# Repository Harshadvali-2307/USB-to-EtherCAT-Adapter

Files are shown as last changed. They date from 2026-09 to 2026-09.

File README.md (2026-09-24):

# USB-to-EtherCAT-Adapter
STM32-based USB to EtherCAT adapter board using the LAN9252 EtherCAT controller.
Topics:
ethercat stm32 lan9252 usb embedded-systems pcb-design hardware industrial-automation electronics
Hardware design files and documentation for a USB-to-EtherCAT adapter board based on STM32 and LAN9252.

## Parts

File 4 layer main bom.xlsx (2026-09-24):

Reference | Value | Datasheet | Footprint | DNP | Exclude from BOM | Exclude from Board | Qty | manufacture number | MANUFACTURER
C1,C2,C3,C4,C20,C21 | 12pF | ~https://datasheets.kyocera-avx.com/600S.pdf | Capacitor_SMD:C_0805_2012Metric |  |  |  | 6 | 600S120JT250XT4K | KYOCERA AVX
C5 | 2.2uF | https://www.mouser.in/datasheet/3/72/1/T491C335K036AT.pdf | Capacitor_SMD:C_0805_2012Metric |  |  |  | 1 | 0805X225M100CT | Walsin
C6,C7,C8,C9,C10,C11,C14,C15,C16,C19,C22,C23,C24,C25,C26,C27,C30,C31,C32,C33,C34,C35 | 0.1uF | ~https://mm.digikey.com/Volume0/opasdata/d220001/medias/docus/6490/3372_0805B104K500BD.pdf | Capacitor_SMD:C_0805_2012Metric |  |  |  | 22 | 0805B104K500BD | Aillen
C12,C13 | 0.022uF | https://mm.digikey.com/Volume0/opasdata/d220001/medias/docus/5660/3372_0805B223K101BD.pdf | Capacitor_SMD:C_0805_2012Metric |  |  |  | 2 | 0805B223K101BD | Aillen
C17,C18 | 10uF | https://www.mouser.in/datasheet/3/72/1/KEM_T2009_T495.pdf,~ | Capacitor_SMD:C_1206_3216Metric |  |  |  | 2 | T495C106M025ATE300 | KEMET
C28 | 1uF | https://mm.digikey.com/Volume0/opasdata/d220001/medias/docus/5660/3372_0805B105K100CC.pdf | Capacitor_SMD:C_0805_2012Metric |  |  |  | 1 | 0805B105K100CC | Aillen
C29 | 470pF | ~https://mm.digikey.com/Volume0/opasdata/d220001/medias/docus/5660/3372_0805B471K101BD.pdf | Capacitor_SMD:C_0805_2012Metric |  |  |  | 1 | 0805B471K101BD | Aillen
D1 | ESD9B3.3ST5G | https://www.onsemi.com/pub/Collateral/ESD9B-D.PDF | Diode_SMD:D_SOD-923 |  |  |  | 1 | ESD9B3.3ST5G | onsemi
D2,D3 | LED | ~https://www.we-online.com/components/products/datasheet/150080RS75000.pdf | LED_SMD:LED_0805_2012Metric |  |  |  | 2 | 150080RS75000 | WÃƒÂ¼rth Elektronik
FB1,FB2,FB3,FB4,FB5 | FerriteBead | https://www.laird.com/sites/default/files/mi0805k400r-10-datasheet.pdf | Capacitor_SMD:C_0805_2012Metric |  |  |  | 5 | MI0805K400R-10 | Laird-Signal Integrity Products
H1,H2,H3,H4 | MountingHole | ~ | MountingHole:MountingHole_2.1mm |  | Excluded from BOM |  | 4
J1,J2 | RJ45_Hanrun_HR911105A_Horizontal | https://datasheet.lcsc.com/lcsc/1811141815_HANRUN-Zhongshan-HanRun-Elec-HR911105A_C12074.pdf | Connector_RJ:RJ45_Hanrun_HR911105A_Horizontal |  |  |  | 2 | HR911105A | Hanrun Electronics
J3 | Conn_01x04_Pin | ~https://content.harwin.com/m/0351a4d2df127c05/original/DRG-00093-Technical-Drawing-Datasheet-D01-992-pdf.pdf | Connector_PinHeader_2.54mm:PinHeader_1x04_P2.54mm_Vertical |  |  |  | 1 | D01-9922046 | Harwin Inc.
J4 | UP2-AH-1-TH | https://www.sameskydevices.com/product/resource/up2-ah-th.pdf | usb type c:usb cup type |  |  |  | 1 | UP2-AH-1-TH | Same Sky (Formerly CUI Devices)
R1,R2,R3,R4,R24 | 10K | https://yageogroup.com/content/datasheet/asset/file/PYU-RC_GROUP_51_ROHS_L | Resistor_SMD:R_0805_2012Metric |  |  |  | 5 | RC0805JR-0710KL | YAGEO
R5,R6,R7,R8,R12,R13,R14,R15 | 49.9R | https://www.vishay.com/docs/20043/crcwhpe3.pdf | Resistor_SMD:R_0805_2012Metric |  |  |  | 8 | CRCW080549R9FKEAHP | Vishay Dale
R9,R11,R16,R17 | 0R | ~https://yageogroup.com/content/datasheet/asset/file/PYU-RC_GROUP_51_ROHS_L | Resistor_SMD:R_0805_2012Metric |  |  |  | 4 | RC0805JR-070RL | YAGEO
R10,R18,R19,R25 | 220R | ~https://www.te.com/commerce/DocumentDelivery/DDEController?Action=srchrtrv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 | Resistor_SMD:R_0805_2012Metric |  |  |  | 4 | CRGCQ0805F220R | TE Connectivity Passive Product
R20,R21,R22 | 4.7K | https://industrial.panasonic.com/cdbs/www-data/pdf/RDO0000/AOA0000C331.pdf | Resistor_SMD:R_0805_2012Metric |  |  |  | 3 | ERJ-P06J472V | Panasonic Electronic Components
R23 | 12.1K | https://www.vishay.com/docs/28773/crcwce3.pdf | Resistor_SMD:R_0805_2012Metric |  |  |  | 1 | CRCW080512K1FKEAC | Vishay Dale
SW2 | SW_Push | ~~https://www.te.com/commerce/DocumentDelivery/DDEController?Action=srchrtrv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 | Button_Switch_SMD:SW_Push_SPST_NO_Alps_SKRK |  |  |  | 1 | 1571563-6 | TE Connectivity / P&B
U1 | STM32F411CEUx | https://www.st.com/resource/en/datasheet/stm32f411ce.pdf | Package_DFN_QFN:QFN-48-1EP_7x7mm_P0.5mm_EP5.6x5.6mm |  |  |  | 1 | STM32F411CEU6TR | STMicroelectronics
U2 | AMS1117-3.3 | http://www.advanced-monolithic.com/pdf/ds1117.pdf | Package_TO_SOT_SMD:SOT-223-3_TabPin2 |  |  |  | 1 | AMS1117-3.3 | EVVO
U3 | 24FC512-I/ST | https://ww1.microchip.com/downloads/en/DeviceDoc/24AA512-24LC512-24FC512-512K-Bit-I2C-Serial-EEPROM-20001754Q.pdf | usb type c:24FC512 |  |  |  | 1 | 24FC512-I/ST | Microchip Technology
U4 | LAN9252I_ML | https://ww1.microchip.com/downloads/aemDocuments/documents/OTH/ProductDocuments/DataSheets/00001909A.pdf | usb type c:LAM ML IC |  |  |  | 1 | LAN9252I/ML | Microchip Technology
Y1,Y3 | 25MHz | https://mm.digikey.com/Volume0/opasdata/d220001/medias/docus/5561/JWT49S-SMD%20Spec.pdf | Crystal:Crystal_SMD_HC49-SD |  |  |  | 2 | SD2025M00012T1521006 | Hefei Jingweite Electronics Co., Ltd.
Y2 | 32.768KHz | https://www.yic.com.tw/wp-content/uploads/2025/04/YIC-3215A-Series.pdf | Crystal:Crystal_SMD_3215-2Pin_3.2x1.5mm |  |  |  | 1 | 32.768K12.5PI/3215A | YIC

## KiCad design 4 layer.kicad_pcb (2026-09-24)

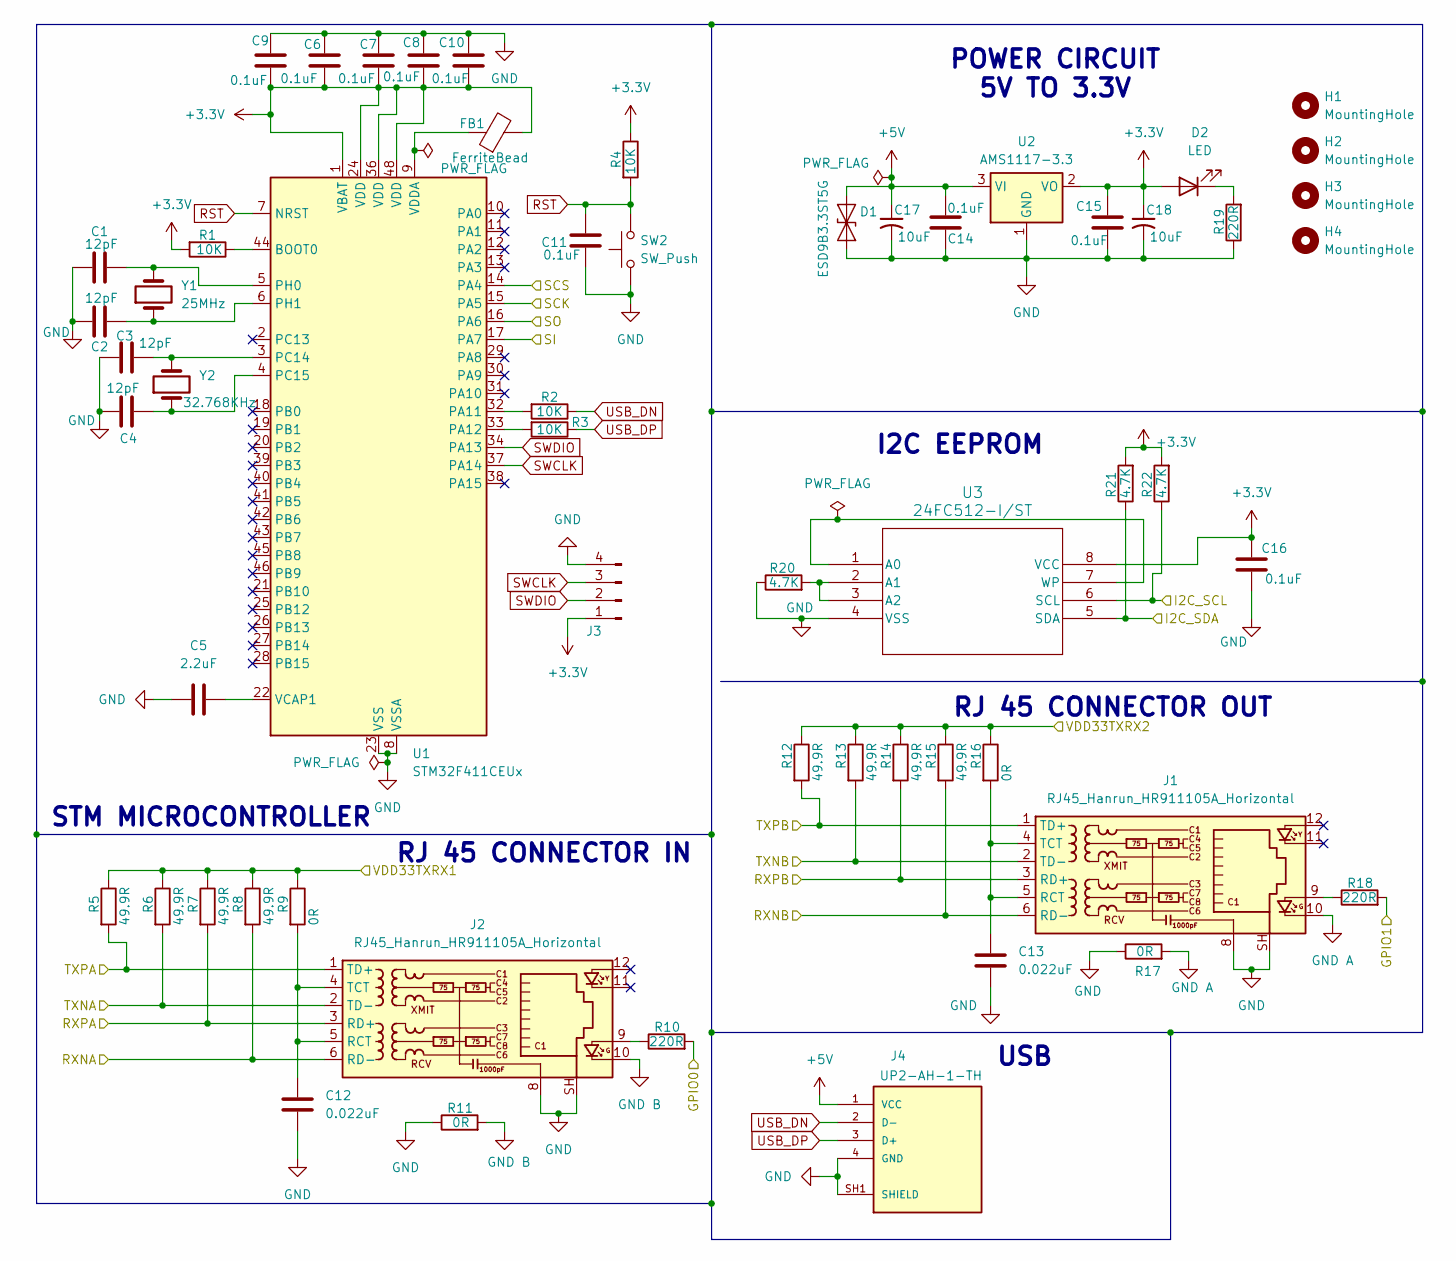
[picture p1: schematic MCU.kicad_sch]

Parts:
C1, C2, C3, C4: 12pF; C_0805_2012Metric
C5: 2.2uF; C_0805_2012Metric
C6, C7, C8, C9, C10, C11, C14, C15, C16: 0.1uF; C_0805_2012Metric
C12, C13: 0.022uF; C_0805_2012Metric
C17, C18: 10uF; C_1206_3216Metric
D1: ESD9B3.3ST5G; D_SOD-923
D2: LED; LED_0805_2012Metric
FB1: FerriteBead; C_0805_2012Metric
H1, H2, H3, H4: MountingHole; MountingHole_2.1mm
J1, J2: RJ45_Hanrun_HR911105A_Horizontal
J3: Conn_01x04_Pin; PinHeader_1x04_P2.54mm_Vertical
J4: UP2-AH-1-TH; usb cup type
R1, R2, R3, R4: 10K; R_0805_2012Metric
R5, R6, R7, R8, R12, R13, R14, R15: 49.9R; R_0805_2012Metric
R9, R11, R16, R17: 0R; R_0805_2012Metric
R10, R18, R19: 220R; R_0805_2012Metric
R20, R21, R22: 4.7K; R_0805_2012Metric
SW2: SW_Push; SW_Push_SPST_NO_Alps_SKRK
U1: STM32F411CEUx; QFN-48-1EP_7x7mm_P0.5mm_EP5.6x5.6mm
U2: AMS1117-3.3; SOT-223-3_TabPin2
U3: 24FC512-I/ST; 24FC512
Y1: 25MHz; Crystal_SMD_HC49-SD
Y2: 32.768KHz; Crystal_SMD_3215-2Pin_3.2x1.5mm

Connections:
+3.3V: C6.1, C7.1, C8.1, C9.1, C10.1, C15.2, C16.2, C18.1, D2.2 (A), FB1.2, J3.1, R1.2, R4.1, R21.2, R22.2, U1.1 (VBAT), U1.24 (VDD), U1.36 (VDD), U1.48 (VDD), U2.2 (VO), U3.8 (VCC); also elsewhere on the board
+5V: C14.1, C17.1, D1.1 (A1), J4.1 (VCC), U2.3 (VI)
/LAN925I/GPIO0: R10.2; also elsewhere on the board
/LAN925I/GPIO1: R18.2; also elsewhere on the board
/LAN925I/I2C_SCL: R21.1, U3.5 (SDA); also elsewhere on the board
/LAN925I/I2C_SDA: R22.1, U3.6 (SCL); also elsewhere on the board
/LAN925I/RXNA: J2.6 (RD-), R8.2; also elsewhere on the board
/LAN925I/RXNB: J1.6 (RD-), R15.2; also elsewhere on the board
/LAN925I/RXPA: J2.3 (RD+), R7.2; also elsewhere on the board
/LAN925I/RXPB: J1.3 (RD+), R14.2; also elsewhere on the board
/LAN925I/SCK: U1.15 (PA5); also elsewhere on the board
/LAN925I/SCS: U1.14 (PA4); also elsewhere on the board
/LAN925I/SI: U1.17 (PA7); also elsewhere on the board
/LAN925I/SO: U1.16 (PA6); also elsewhere on the board
/LAN925I/TXNA: J2.2 (TD-), R6.2; also elsewhere on the board
/LAN925I/TXNB: J1.2 (TD-), R13.2; also elsewhere on the board
/LAN925I/TXPA: J2.1 (TD+), R5.2; also elsewhere on the board
/LAN925I/TXPB: J1.1 (TD+), R12.2; also elsewhere on the board
GND: C1.1, C2.1, C3.1, C4.1, C5.1, C6.2, C7.2, C8.2, C9.2, C10.2, C11.1, C12.1, C13.1, C14.2, C15.1, C16.1, C17.2, C18.2, D1.2 (A2), J1.8, J1.SH, J2.8, J2.SH, J3.4, J4.4 (GND), J4.SH1 (SHIELD), J4.SH2 (SHIELD), R11.1, R17.1, R19.1, R20.1, SW2.1, U1.8 (VSSA), U1.23 (VSS), U1.35 (VSS), U1.47 (VSS), U1.49 (VSS), U2.1 (GND), U3.4 (VSS); also elsewhere on the board
GND A: J1.10, R17.2
GND B: J2.10, R11.2
unnamed: D2.1 (K), R19.2
unnamed: J1.9, R18.1
unnamed: C13.2, J1.4 (TCT), J1.5 (RCT), R16.2
unnamed: J2.9, R10.1
unnamed: C12.2, J2.4 (TCT), J2.5 (RCT), R9.2
unnamed: R1.1, U1.44 (BOOT0)
unnamed: R2.2, U1.32 (PA11)
unnamed: R3.2, U1.33 (PA12)
unnamed: C3.2, U1.3 (PC14), Y2.2
unnamed: C4.2, U1.4 (PC15), Y2.1
unnamed: C1.2, U1.5 (PH0), Y1.2
unnamed: C2.2, U1.6 (PH1), Y1.1
unnamed: C5.2, U1.22 (VCAP1)
unnamed: FB1.1, U1.9 (VDDA)
unnamed: U3.1 (A0), U3.7 (WP)
unnamed: R20.2, U3.2 (A1), U3.3 (A2)
RST: C11.2, R4.2, SW2.2, U1.7 (NRST)
SWCLK: J3.3, U1.37 (PA14)
SWDIO: J3.2, U1.34 (PA13)
USB_DN: J4.2 (D-), R2.1
USB_DP: J4.3 (D+), R3.1
VDD33TXRX1: R5.1, R6.1, R7.1, R8.1, R9.1; also elsewhere on the board
VDD33TXRX2: R12.1, R13.1, R14.1, R15.1, R16.1; also elsewhere on the board

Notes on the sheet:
RJ 45 CONNECTOR IN
RJ 45 CONNECTOR OUT
POWER CIRCUIT 5V TO 3.3V
STM MICROCONTROLLER
I2C EEPROM
USB

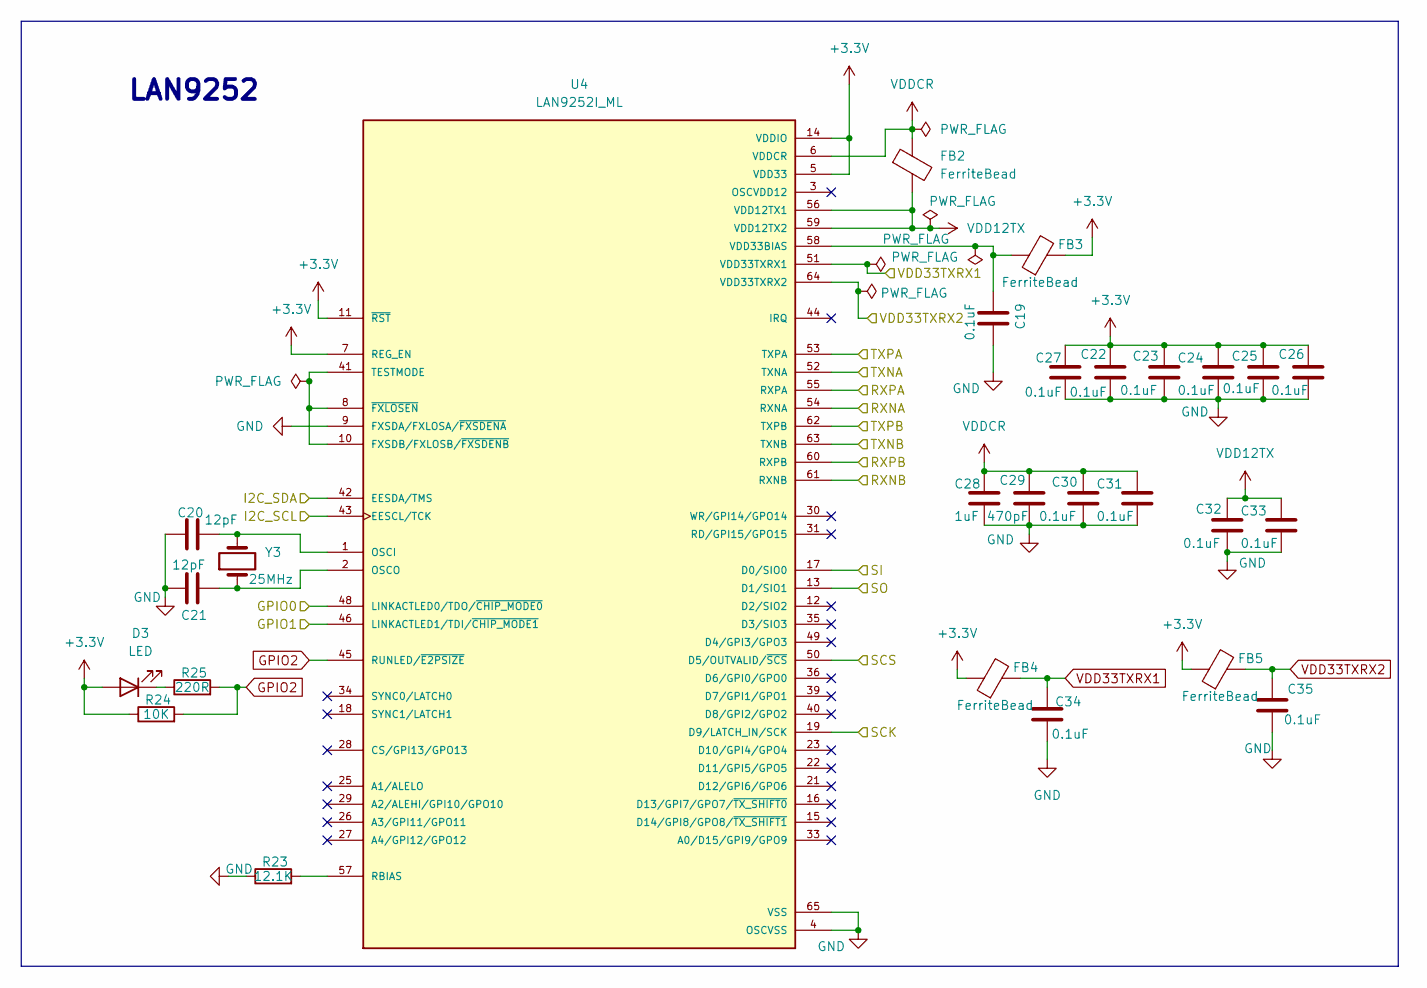
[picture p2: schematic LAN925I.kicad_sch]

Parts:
C19, C22, C23, C24, C25, C26, C27, C30, C31, C32, C33, C34, C35: 0.1uF; C_0805_2012Metric
C20, C21: 12pF; C_0805_2012Metric
C28: 1uF; C_0805_2012Metric
C29: 470pF; C_0805_2012Metric
D3: LED; LED_0805_2012Metric
FB2, FB3, FB4, FB5: FerriteBead; C_0805_2012Metric
R23: 12.1K; R_0805_2012Metric
R24: 10K; R_0805_2012Metric
R25: 220R; R_0805_2012Metric
U4: LAN9252I_ML; LAM ML IC
Y3: 25MHz; Crystal_SMD_HC49-SD

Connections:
+3.3V: C22.2, C23.2, C24.2, C25.2, C26.2, C27.2, D3.2 (A), FB3.2, FB4.1, FB5.1, R24.1, U4.5 (VDD33), U4.7 (REG_EN), U4.11 (~RST), U4.14 (VDDIO), U4.20 (VDDIO), U4.32 (VDDIO), U4.37 (VDDIO), U4.47 (VDDIO); also elsewhere on the board
/LAN925I/GPIO0: U4.48 (LINKACTLED0/TDO/~CHIP_MODE0); also elsewhere on the board
/LAN925I/GPIO1: U4.46 (LINKACTLED1/TDI/~CHIP_MODE1); also elsewhere on the board
/LAN925I/I2C_SCL: U4.43 (EESCL/TCK); also elsewhere on the board
/LAN925I/I2C_SDA: U4.42 (EESDA/TMS); also elsewhere on the board
/LAN925I/RXNA: U4.54 (RXNA); also elsewhere on the board
/LAN925I/RXNB: U4.61 (RXNB); also elsewhere on the board
/LAN925I/RXPA: U4.55 (RXPA); also elsewhere on the board
/LAN925I/RXPB: U4.60 (RXPB); also elsewhere on the board
/LAN925I/SCK: U4.19 (D9/LATCH_IN/SCK); also elsewhere on the board
/LAN925I/SCS: U4.50 (D5/OUTVALID/~SCS); also elsewhere on the board
/LAN925I/SI: U4.17 (D0/SIO0); also elsewhere on the board
/LAN925I/SO: U4.13 (D1/SIO1); also elsewhere on the board
/LAN925I/TXNA: U4.52 (TXNA); also elsewhere on the board
/LAN925I/TXNB: U4.63 (TXNB); also elsewhere on the board
/LAN925I/TXPA: U4.53 (TXPA); also elsewhere on the board
/LAN925I/TXPB: U4.62 (TXPB); also elsewhere on the board
GND: C19.1, C20.1, C21.1, C22.1, C23.1, C24.1, C25.1, C26.1, C27.1, C28.1, C29.1, C30.1, C31.1, C32.1, C33.1, C34.1, C35.1, R23.1, U4.4 (OSCVSS), U4.9 (FXSDA/FXLOSA/~FXSDENA), U4.65 (VSS), U4.66, U4.67, U4.68, U4.69, U4.70, U4.71, U4.72, U4.73, U4.74, U4.75, U4.76, U4.77, U4.78, U4.79, U4.80, U4.81, U4.82, U4.83, U4.84, U4.85, U4.86, U4.87, U4.88, U4.89, U4.90, U4.91, U4.92, U4.93, U4.94, U4.95, U4.96, U4.97, U4.98, U4.99, U4.100, U4.101; also elsewhere on the board
GPIO2: R24.2, R25.2, U4.45 (RUNLED/~E2PSIZE)
unnamed: D3.1 (K), R25.1
unnamed: U4.8 (~FXLOSEN), U4.10 (FXSDB/FXLOSB/~FXSDENB), U4.41 (TESTMODE)
unnamed: C20.2, U4.1 (OSCI), Y3.2
unnamed: C21.2, U4.2 (OSCO), Y3.1
unnamed: R23.2, U4.57 (RBIAS)
unnamed: C19.2, FB3.1, U4.58 (VDD33BIAS)
VDD12TX: C32.2, C33.2, FB2.2, U4.56 (VDD12TX1), U4.59 (VDD12TX2)
VDD33TXRX1: C34.2, FB4.2, U4.51 (VDD33TXRX1); also elsewhere on the board
VDD33TXRX2: C35.2, FB5.2, U4.64 (VDD33TXRX2); also elsewhere on the board
VDDCR: C28.2, C29.2, C30.2, C31.2, FB2.1, U4.6 (VDDCR), U4.24 (VDDCR), U4.38 (VDDCR)

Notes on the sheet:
LAN9252

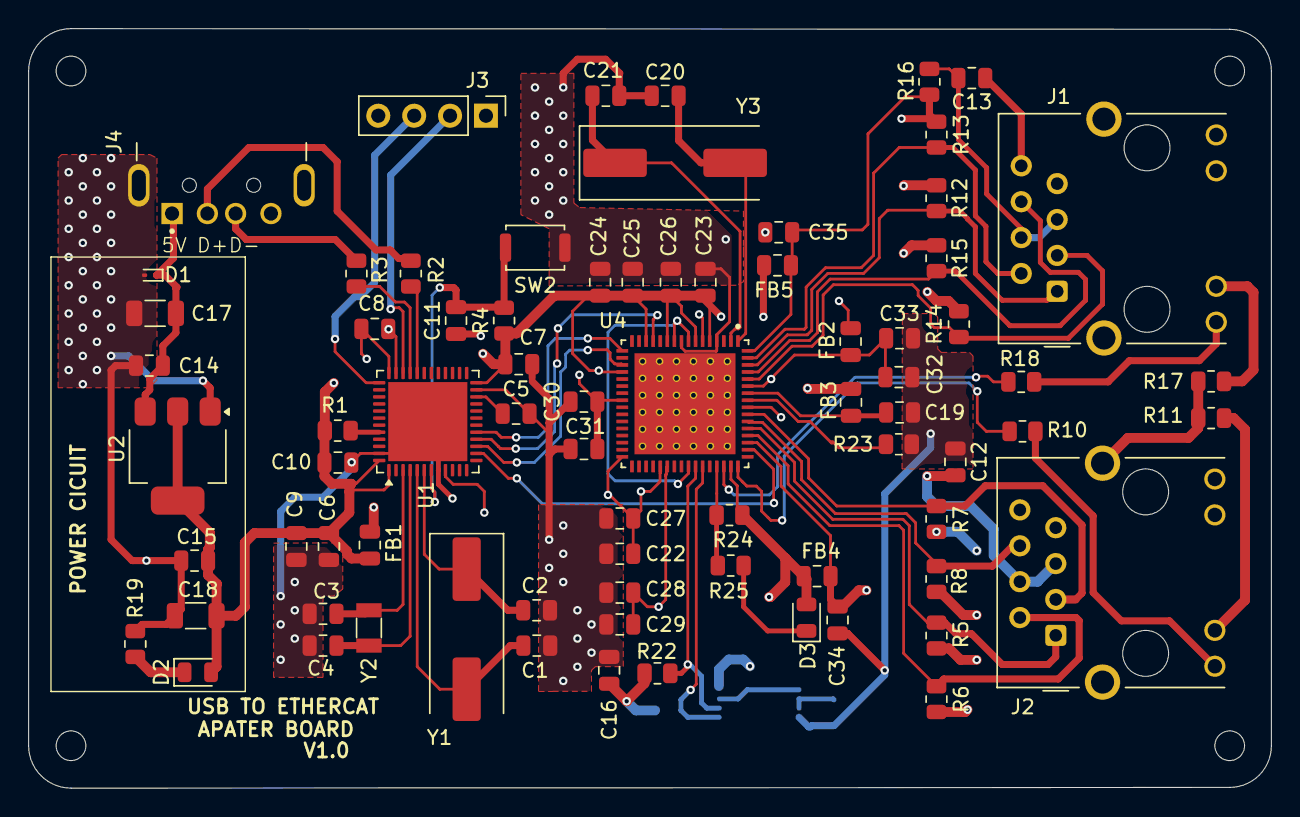
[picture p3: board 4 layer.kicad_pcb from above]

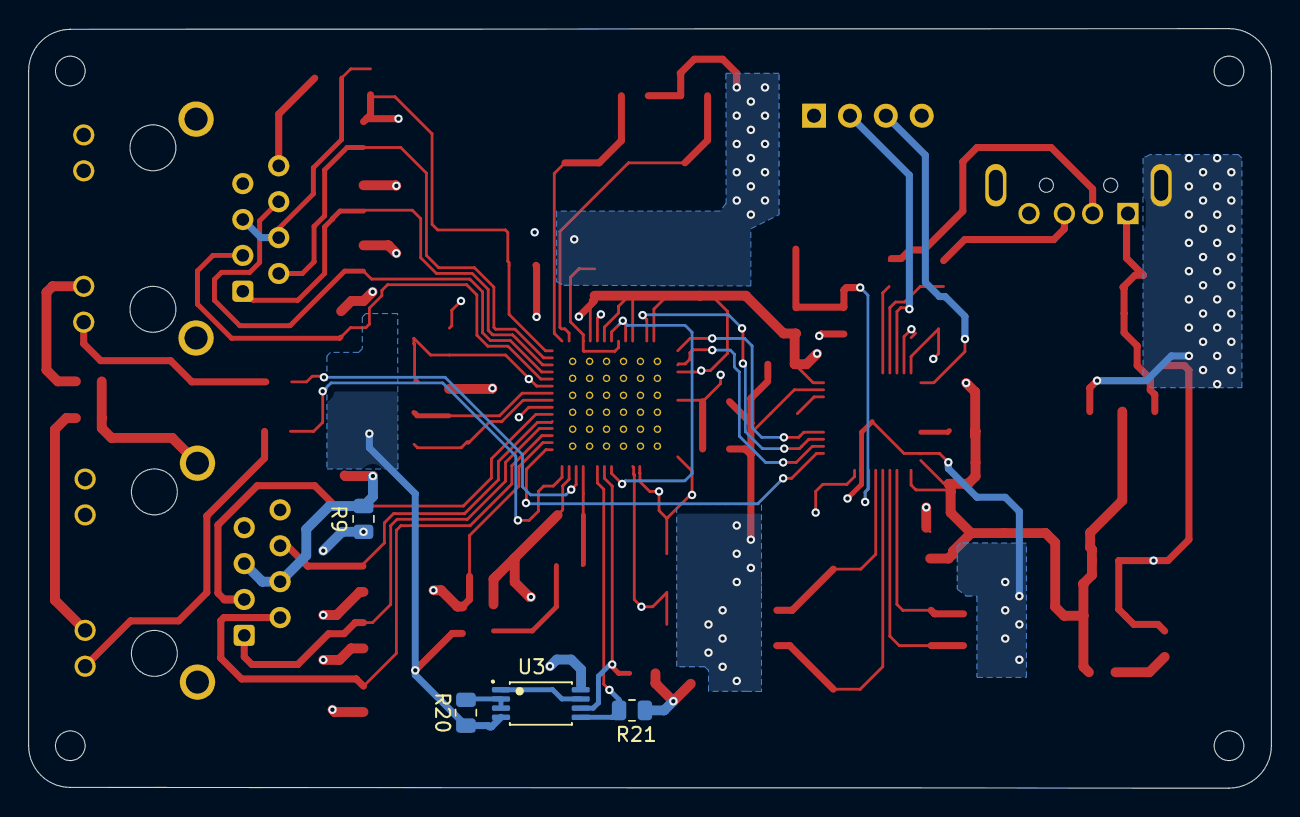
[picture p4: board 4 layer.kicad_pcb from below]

Board: 4 copper layers, 87.9 x 53.8 mm, 84 parts (4 on the bottom side), 53 nets.
